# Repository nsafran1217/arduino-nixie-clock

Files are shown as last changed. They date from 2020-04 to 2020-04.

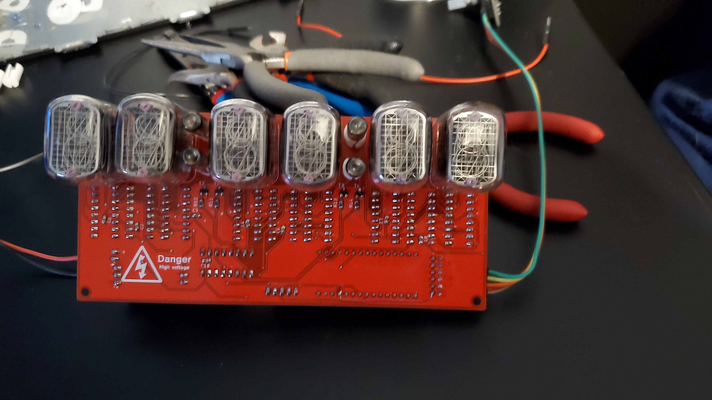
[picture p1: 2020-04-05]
top.jpg

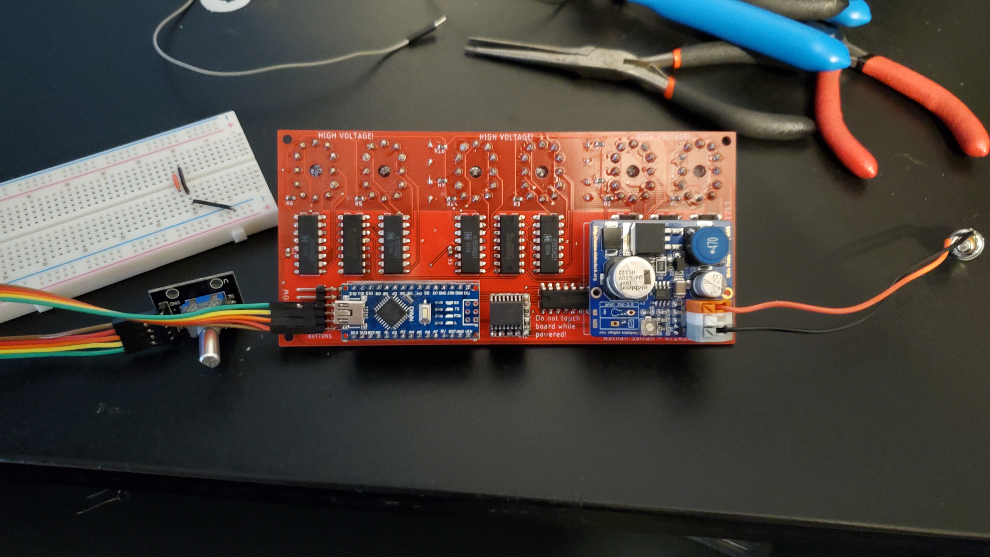
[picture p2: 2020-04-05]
back.jpg

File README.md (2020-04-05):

# arduino-nixie-clock
Custom IN-12A (ИН-12А) Nixie clock with RTC and arduino

This code is messy and specific to my board design. 

I made one change after recieving the boards. I needed a 5volt power pin for the rotary encoder. I scrapped up a trace to a digital pin on the button header and added a bodge wire for 5 volts. You will need to get 5v to your rotary encoder

https://www.amazon.com/HiLetgo-Degrees-Rotary-Encoder-Arduino/dp/B07WZF1TXX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

# Main Modes
Adjust by turning rotary encoder
* 0: Time mode
* 1: Date mode
* 2: Rotate mode

Rotate mode rotates between date and time at a set interval

# Settings menu
Enter settings menu by pressing rotary encoder

Press it again to change the selected setting

* 0: Exit settings menu
* 1: Set Time
* 2: Set Date
* 3: Set rotation interval in seconds
* 4: Select 12 or 24 hour display
* 5: Set the time transition mode. currently there is only two. 0 for normal and 1 for slot machine effect.
* 6: Set time to turn display off then back on. First digit is the hour it turns off. second is the hour it turns back on
* 7: Set anti cathode poison time. Fist digit is the minute that the first run will happen on. Second is the interval in minutes that it runs

example: 15 - 10. the first run will happen at 0:15 and the next run will happen at 0:25. Add 10 minutes for every run after

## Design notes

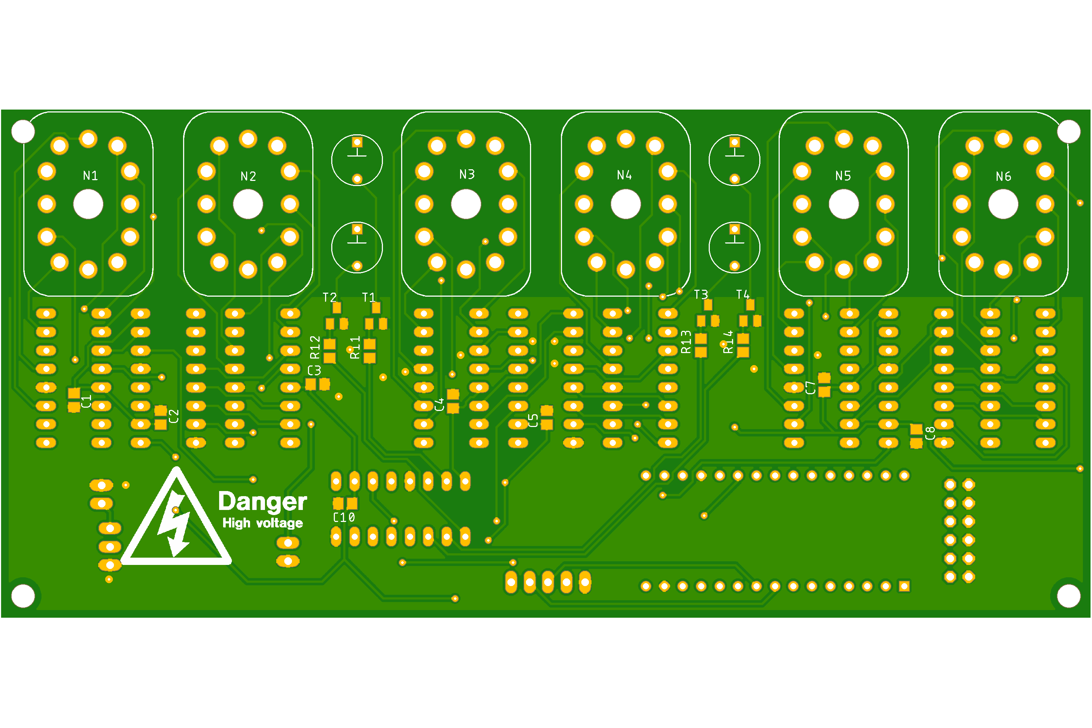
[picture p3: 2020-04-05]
front.png

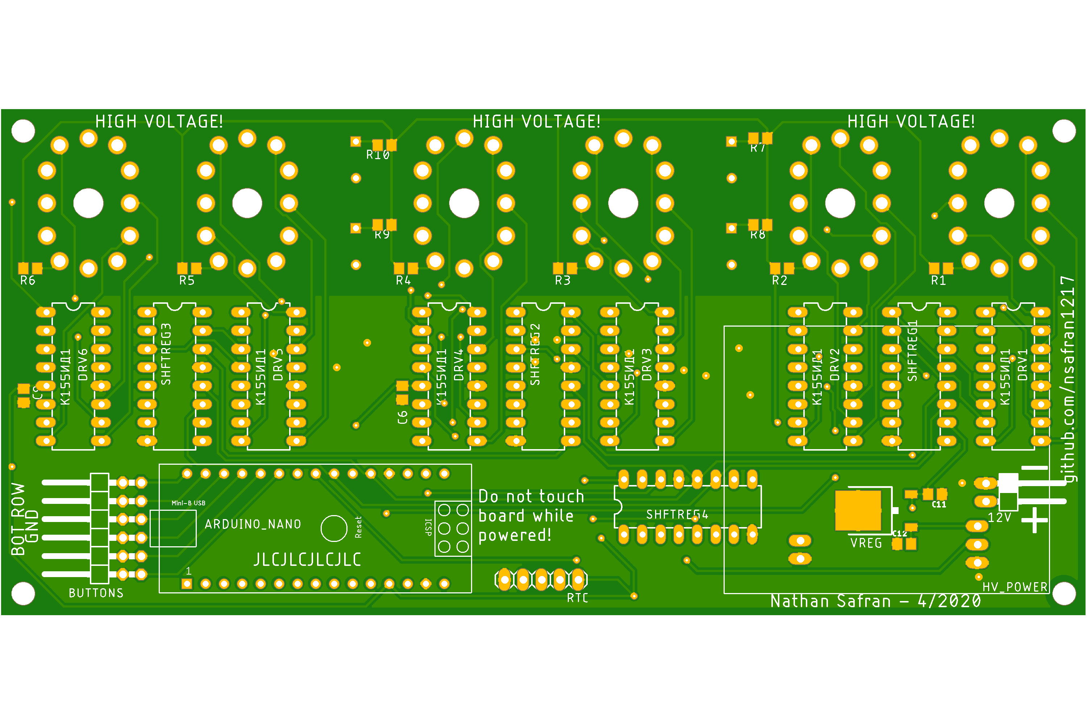
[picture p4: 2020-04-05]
bottom.png

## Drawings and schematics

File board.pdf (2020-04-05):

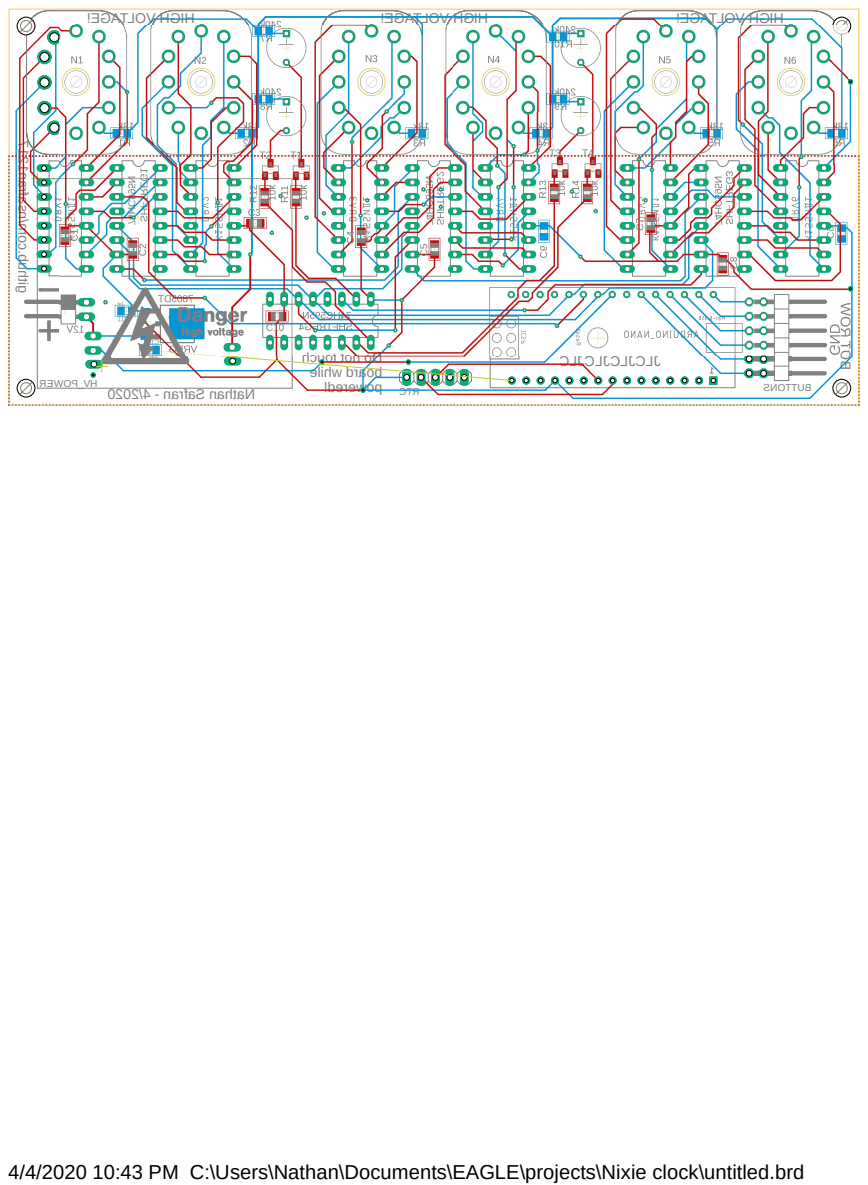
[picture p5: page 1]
BUTTONS HV_POWER RTC; board while powered!

HIGH VOLTAGE! HIGH VOLTAGE! HIGH VOLTAGE!

JLCJLCJLCJLC github.com/nsafran1217

Nathan Safran - 4/2020 BOT ROW

Do not touch

4/4/2020 10:43 PM C:\Users\Nathan\Documents\EAGLE\projects\Nixie clock\untitled.brd

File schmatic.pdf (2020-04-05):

4/4/2020 10:43 PM f=0.57 C:\Users\Nathan\Documents\EAGLE\projects\Nixie clock\untitled.sch (Sheet: 1/1) К155ИД¹ | К155ИД¹ | К155ИД¹ | К155ИД¹ | К155ИД¹ | К155ИД¹ 74HC⁵⁹⁵N | 74HC⁵⁹⁵N | 74HC⁵⁹⁵N +5V | GNDGND | GND | GND

# INS-1

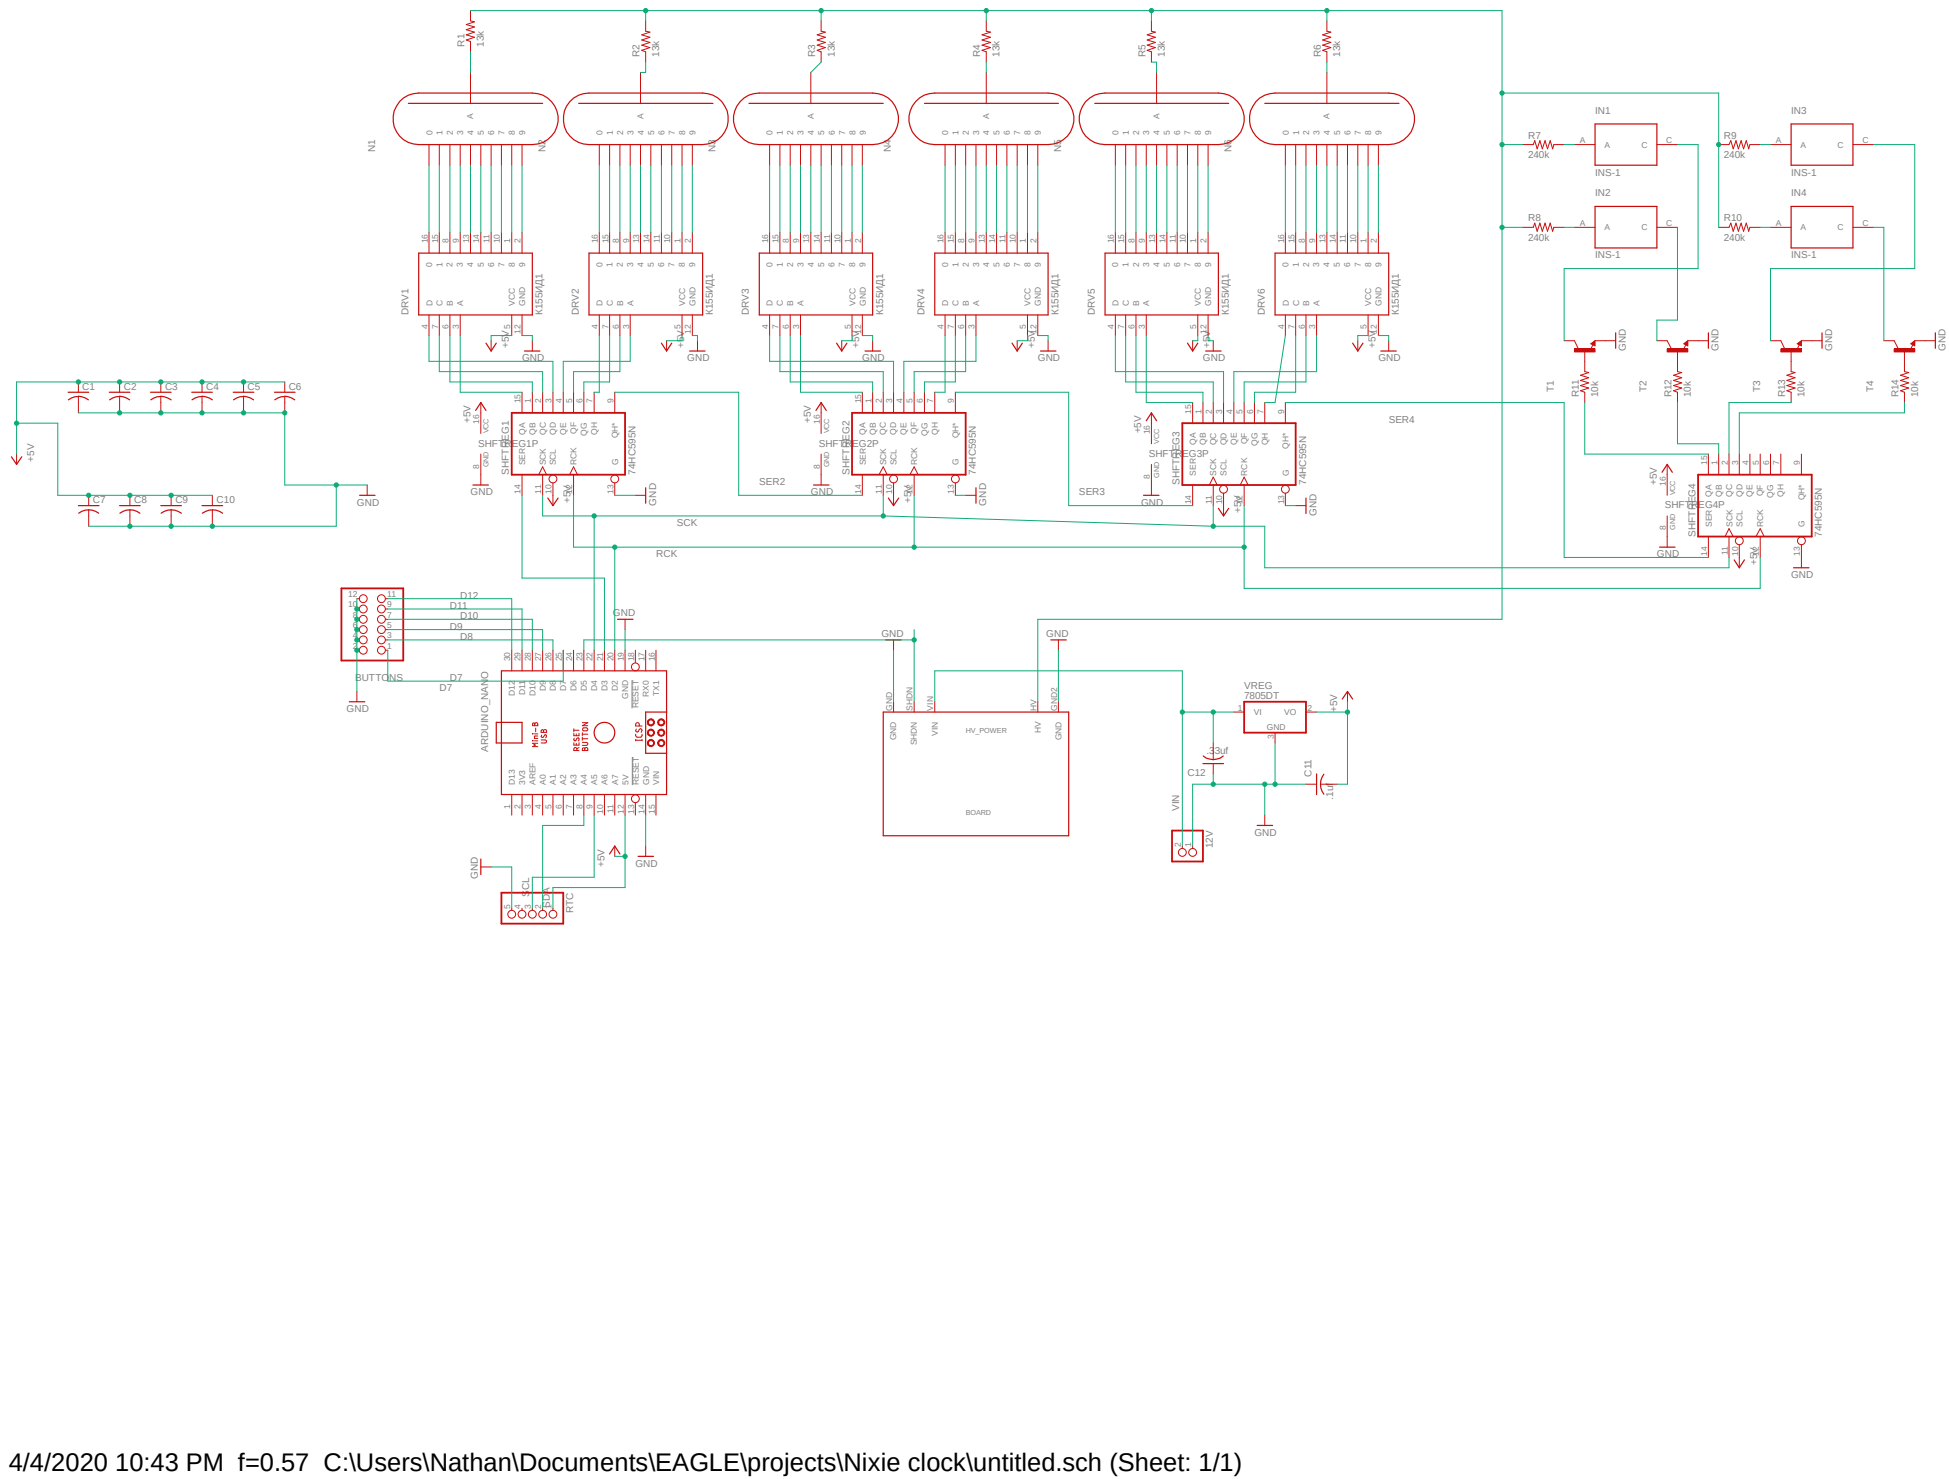
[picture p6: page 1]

7 SCL 10 SCK 11 RCK 12 G 13 SER 14 QA 15 QH* 9 SHFTREG4 R11 R12 R13 R14 8 16 GND VCC SHFTREG1P 8 16 GND VCC SHFTREG2P 8 16 GND VCC SHFTREG3P 8 16 GND VCC SHFTREG4P C1 C2 C3 C4 C5 C6 T1T2T3T4

7 SCL 10 SCK 11 RCK 12 G 13 SER 14 QA 15 QH* 9 SHFTREG1 QB

7 SCL 10 SCK 11 RCK 12 G 13 SER 14 QA 15 QH* 9 SHFTREG3 TX1 16 RX0 17 RESET 18 GND 19 D2 20 D3 21 D4 22 D5 23 D6 24 D7 25 D8 26 D9 27 D10 28 D11 29 D12 30 D13

7 SCL 10 SCK 11 RCK 12 G 13 SER 14 QA 15 QH* 9 SHFTREG2 QB

9 A6 10 A7 11 5V 12 RESET 13 GND 14 VIN 15 ARDUINO_NANO GND GND SHDN SHDN VIN VIN HV HV GND GND2 HV_POWER

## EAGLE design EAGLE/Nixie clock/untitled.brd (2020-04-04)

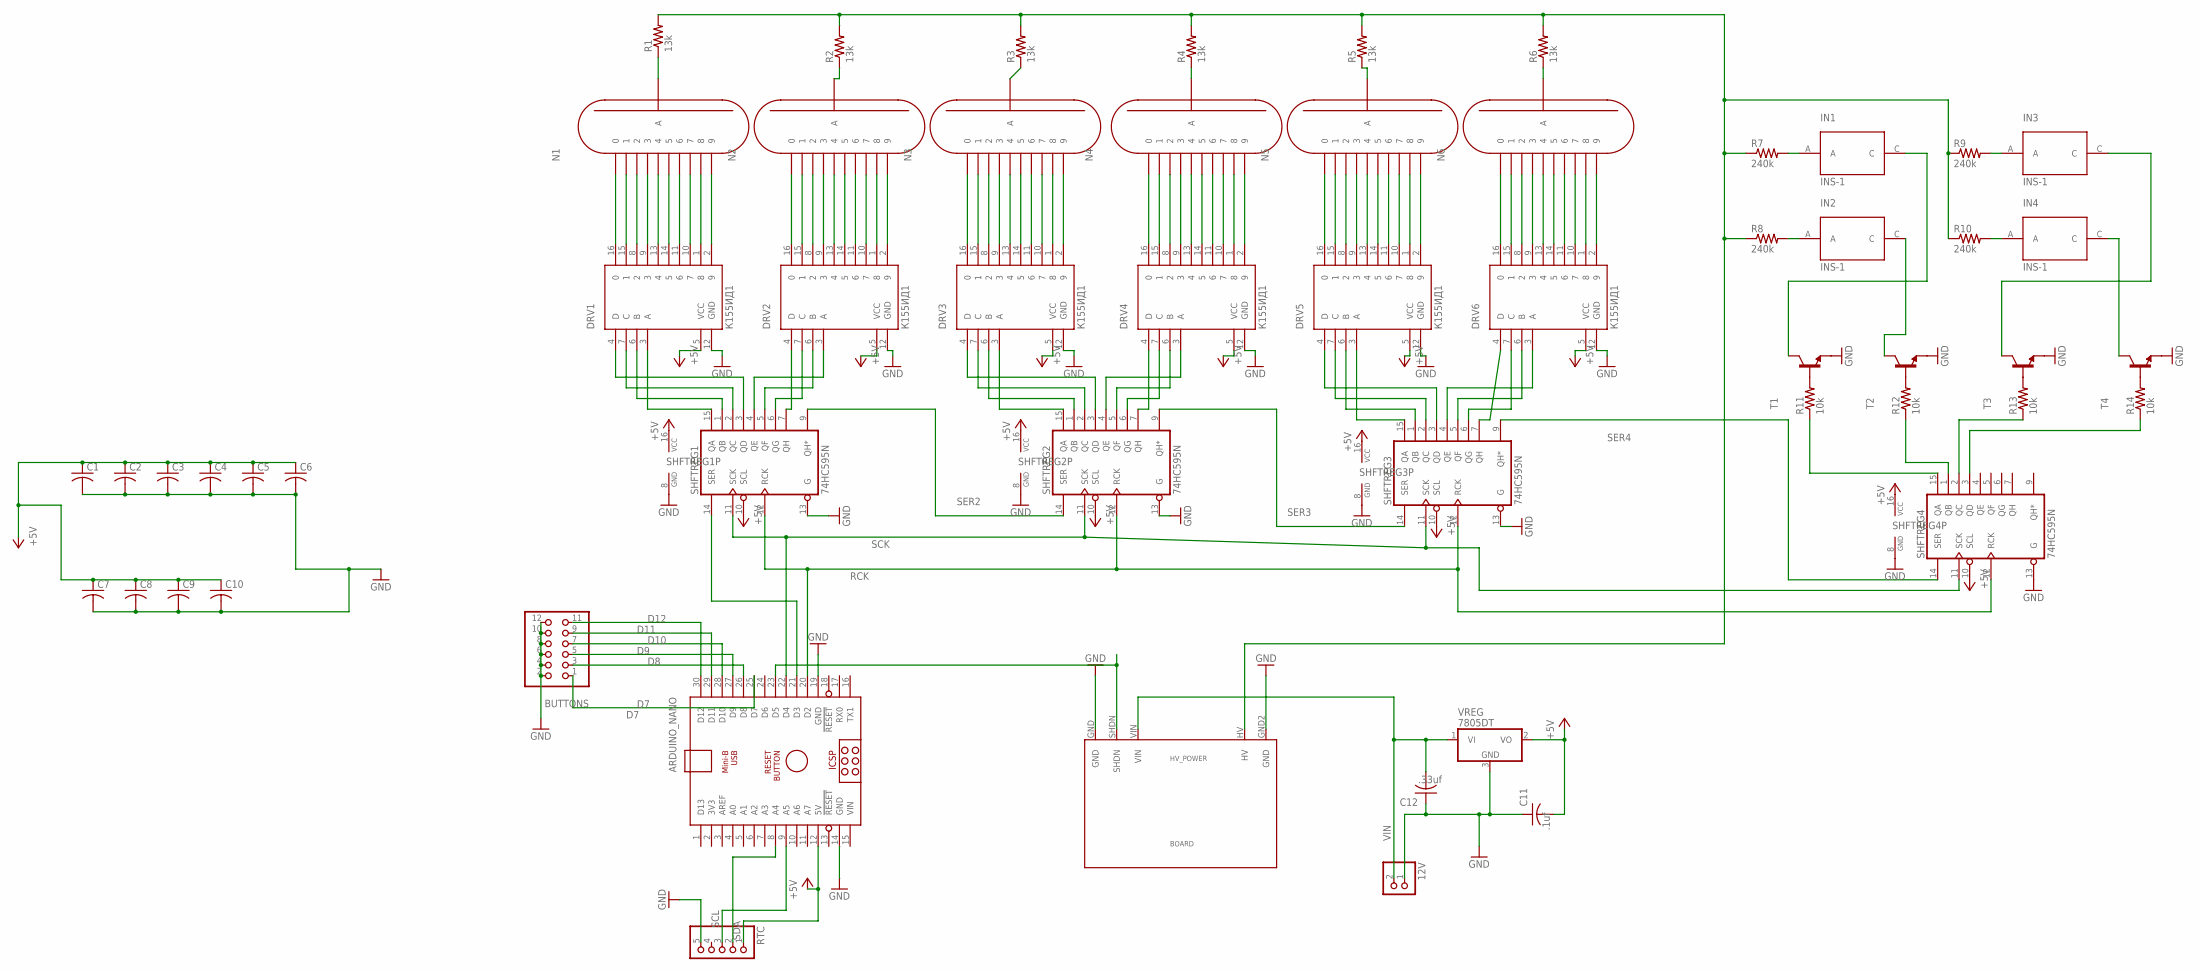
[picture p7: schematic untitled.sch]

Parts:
12V: PINHD-1X2/90; 1X02/90
ARDUINO_NANO: ARDUINO_NANO
BUTTONS: PINHD-2X6/90; 2X06/90
C1, C2, C3, C4, C5, C6, C7, C8, C9, C10: C-USC0805; C0805
C11: .1uf; C0805
C12: .33uf; C0805
DRV1, DRV2, DRV3, DRV4, DRV5, DRV6: К155ИД1; DIL16
HV_POWER: BOARD
IN1, IN2, IN3, IN4: INS-1
N1, N2, N3, N4, N5, N6: IN-12A; IN-12
R1, R2, R3, R4, R5, R6: 13k; R0805
R7, R8, R9, R10: 240k; R0805
R11, R12, R13, R14: 10k; R0805
RTC: PINHD-1X5; 1X05
SHFTREG1, SHFTREG2, SHFTREG3, SHFTREG4: 74HC595N; DIL16
T1, T2, T3, T4: MMBTA42LT1-NPN-SOT23-BEC; SOT23-BEC
VREG: 7805DT; TO252

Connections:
+5V: ARDUINO_NANO.12 (5V), C1.1, C2.1, C3.1, C4.1, C5.1, C6.1, C7.1, C8.1, C9.1, C10.1, C11.2, DRV1.5 (VCC), DRV2.5 (VCC), DRV3.5 (VCC), DRV4.5 (VCC), DRV5.5 (VCC), DRV6.5 (VCC), RTC.1, SHFTREG1.10 (SCL), SHFTREG1.16 (VCC), SHFTREG2.10 (SCL), SHFTREG2.16 (VCC), SHFTREG3.10 (SCL), SHFTREG3.16 (VCC), SHFTREG4.10 (SCL), SHFTREG4.16 (VCC), VREG.2 (VO)
D7: ARDUINO_NANO.25 (D7), BUTTONS.1
D8: ARDUINO_NANO.26 (D8), BUTTONS.3
D9: ARDUINO_NANO.27 (D9), BUTTONS.5
D10: ARDUINO_NANO.28 (D10), BUTTONS.7
D11: ARDUINO_NANO.29 (D11), BUTTONS.9
D12: ARDUINO_NANO.30 (D12), BUTTONS.11
GND: 12V.1, ARDUINO_NANO.14 (GND), ARDUINO_NANO.19 (GND), BUTTONS.2, BUTTONS.4, BUTTONS.6, BUTTONS.8, BUTTONS.10, BUTTONS.12, C1.2, C2.2, C3.2, C4.2, C5.2, C6.2, C7.2, C8.2, C9.2, C10.2, C11.1, C12.1, DRV1.12 (GND), DRV2.12 (GND), DRV3.12 (GND), DRV4.12 (GND), DRV5.12 (GND), DRV6.12 (GND), HV_POWER.GND, HV_POWER.GND2 (GND), RTC.5, SHFTREG1.8 (GND), SHFTREG1.13 (G), SHFTREG2.8 (GND), SHFTREG2.13 (G), SHFTREG3.8 (GND), SHFTREG3.13 (G), SHFTREG4.8 (GND), SHFTREG4.13 (G), T1.E, T2.E, T3.E, T4.E, VREG.3 (GND)
unnamed: DRV4.4 (D), SHFTREG2.7 (QH)
unnamed: DRV1.16 (0), N1.0
unnamed: DRV1.15 (1), N1.1
unnamed: DRV1.8 (2), N1.2
unnamed: DRV1.9 (3), N1.3
unnamed: DRV1.13 (4), N1.4
unnamed: DRV1.11 (6), N1.6
unnamed: DRV1.14 (5), N1.5
unnamed: DRV1.10 (7), N1.7
unnamed: DRV1.1 (8), N1.8
unnamed: DRV1.2 (9), N1.9
unnamed: DRV2.16 (0), N2.0
unnamed: DRV2.15 (1), N2.1
unnamed: DRV2.8 (2), N2.2
unnamed: DRV2.9 (3), N2.3
unnamed: DRV2.13 (4), N2.4
unnamed: DRV2.14 (5), N2.5
unnamed: DRV2.11 (6), N2.6
unnamed: DRV2.10 (7), N2.7
unnamed: DRV2.1 (8), N2.8
unnamed: DRV2.2 (9), N2.9
unnamed: DRV3.16 (0), N3.0
unnamed: DRV3.15 (1), N3.1
unnamed: DRV3.8 (2), N3.2
unnamed: DRV3.9 (3), N3.3
unnamed: DRV3.13 (4), N3.4
unnamed: DRV3.14 (5), N3.5
unnamed: DRV3.11 (6), N3.6
unnamed: DRV3.10 (7), N3.7
unnamed: DRV3.1 (8), N3.8
unnamed: DRV3.2 (9), N3.9
unnamed: DRV4.16 (0), N4.0
unnamed: DRV4.15 (1), N4.1
unnamed: DRV4.8 (2), N4.2
unnamed: DRV4.9 (3), N4.3
unnamed: DRV4.13 (4), N4.4
unnamed: DRV4.14 (5), N4.5
unnamed: DRV4.11 (6), N4.6
unnamed: DRV4.10 (7), N4.7
unnamed: DRV4.1 (8), N4.8
unnamed: DRV4.2 (9), N4.9
unnamed: DRV5.16 (0), N5.0
unnamed: DRV5.15 (1), N5.1
unnamed: DRV5.8 (2), N5.2
unnamed: DRV5.9 (3), N5.3
unnamed: DRV5.13 (4), N5.4
unnamed: DRV5.11 (6), N5.6
unnamed: DRV5.14 (5), N5.5
unnamed: DRV5.10 (7), N5.7
unnamed: DRV5.1 (8), N5.8
unnamed: DRV5.2 (9), N5.9
unnamed: DRV6.16 (0), N6.0
unnamed: DRV6.15 (1), N6.1
unnamed: DRV6.8 (2), N6.2
unnamed: DRV6.9 (3), N6.3
unnamed: DRV6.13 (4), N6.4
unnamed: DRV6.14 (5), N6.5
unnamed: DRV6.11 (6), N6.6
unnamed: DRV6.10 (7), N6.7
unnamed: DRV6.1 (8), N6.8
unnamed: DRV1.3 (A), SHFTREG1.15 (QA)
unnamed: DRV1.6 (B), SHFTREG1.1 (QB)
unnamed: DRV1.7 (C), SHFTREG1.2 (QC)
unnamed: DRV1.4 (D), SHFTREG1.3 (QD)
unnamed: DRV2.3 (A), SHFTREG1.4 (QE)
unnamed: DRV2.6 (B), SHFTREG1.5 (QF)
unnamed: DRV2.7 (C), SHFTREG1.6 (QG)
unnamed: DRV2.4 (D), SHFTREG1.7 (QH)
unnamed: ARDUINO_NANO.23 (D5), HV_POWER.SHDN
unnamed: DRV3.3 (A), SHFTREG2.15 (QA)
unnamed: DRV3.6 (B), SHFTREG2.1 (QB)
unnamed: DRV3.7 (C), SHFTREG2.2 (QC)
unnamed: DRV3.4 (D), SHFTREG2.3 (QD)
unnamed: DRV4.3 (A), SHFTREG2.4 (QE)
unnamed: DRV4.6 (B), SHFTREG2.5 (QF)
unnamed: DRV4.7 (C), SHFTREG2.6 (QG)
unnamed: DRV6.2 (9), N6.9
unnamed: DRV5.3 (A), SHFTREG3.15 (QA)
unnamed: DRV5.6 (B), SHFTREG3.1 (QB)
unnamed: DRV5.7 (C), SHFTREG3.2 (QC)
unnamed: DRV5.4 (D), SHFTREG3.3 (QD)
unnamed: DRV6.3 (A), SHFTREG3.4 (QE)
unnamed: DRV6.6 (B), SHFTREG3.5 (QF)
unnamed: DRV6.7 (C), SHFTREG3.6 (QG)
unnamed: DRV6.4 (D), SHFTREG3.7 (QH)
unnamed: IN1.C, T1.C
unnamed: N1.A, R1.1
unnamed: N2.A, R2.1
unnamed: N3.A, R3.1
unnamed: N4.A, R4.1
unnamed: N5.A, R5.1
unnamed: N6.A, R6.1
unnamed: IN2.A, R8.2
unnamed: IN1.A, R7.2
unnamed: IN3.A, R9.2
unnamed: IN4.A, R10.2
unnamed: HV_POWER.HV, R1.2, R2.2, R3.2, R4.2, R5.2, R6.2, R7.1, R8.1, R9.1, R10.1
unnamed: R11.2, T1.B
unnamed: R12.2, T2.B
unnamed: R13.2, T3.B
unnamed: R11.1, SHFTREG4.15 (QA)
unnamed: R12.1, SHFTREG4.1 (QB)
unnamed: IN3.C, T3.C
unnamed: R13.1, SHFTREG4.2 (QC)
unnamed: R14.1, SHFTREG4.3 (QD)
unnamed: IN4.C, T4.C
unnamed: R14.2, T4.B
unnamed: IN2.C, T2.C
RCK: ARDUINO_NANO.20 (D2), SHFTREG1.12 (RCK), SHFTREG2.12 (RCK), SHFTREG3.12 (RCK), SHFTREG4.12 (RCK)
SCK: ARDUINO_NANO.22 (D4), SHFTREG1.11 (SCK), SHFTREG2.11 (SCK), SHFTREG3.11 (SCK), SHFTREG4.11 (SCK)
SCL: ARDUINO_NANO.9 (A5), RTC.3
SDA: ARDUINO_NANO.8 (A4), RTC.2
SER1: ARDUINO_NANO.21 (D3), SHFTREG1.14 (SER)
SER2: SHFTREG1.9 (QH*), SHFTREG2.14 (SER)
SER3: SHFTREG2.9 (QH*), SHFTREG3.14 (SER)
SER4: SHFTREG3.9 (QH*), SHFTREG4.14 (SER)
VIN: 12V.2, ARDUINO_NANO.15 (VIN), C12.2, HV_POWER.VIN, VREG.1 (VI)

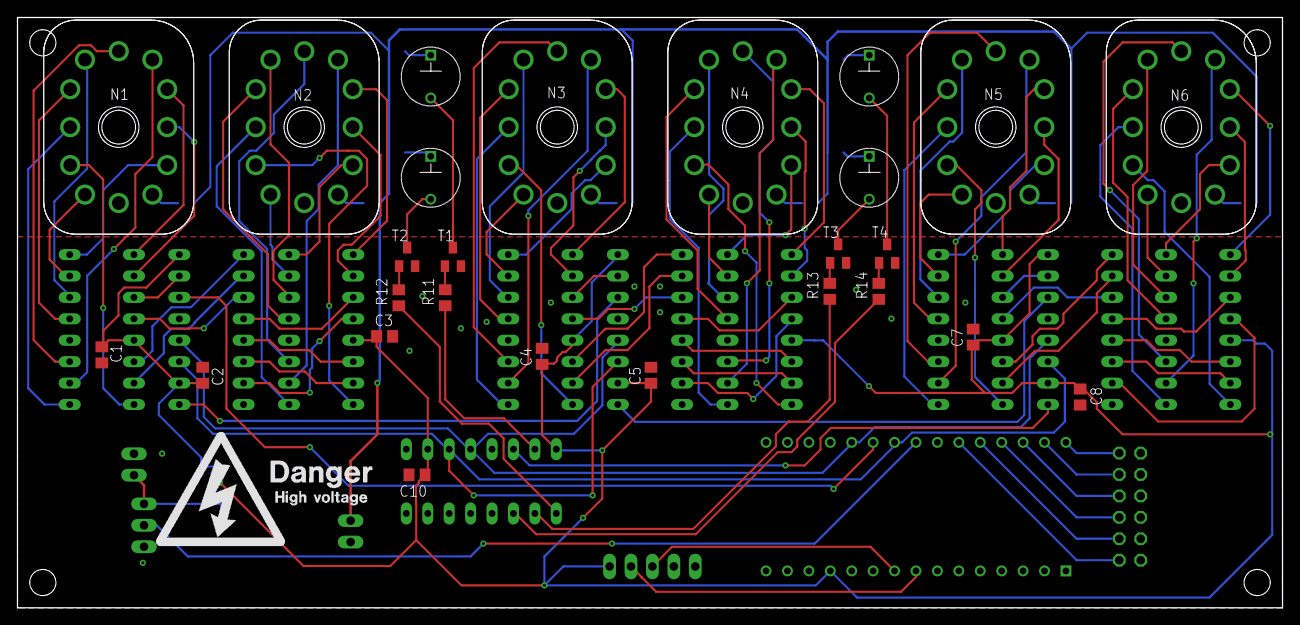
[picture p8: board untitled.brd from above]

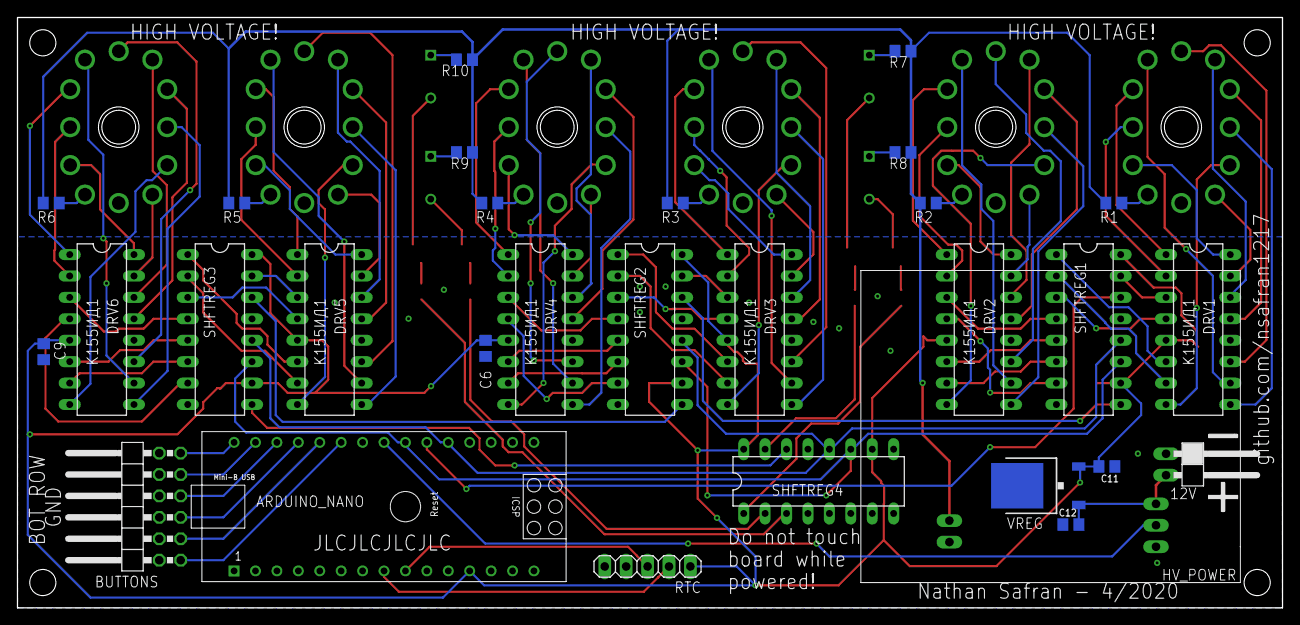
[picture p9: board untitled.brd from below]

Board: 2 copper layers, 150.0 x 70.0 mm, 57 parts (30 on the bottom side), 125 nets.

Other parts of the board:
U$1: HV

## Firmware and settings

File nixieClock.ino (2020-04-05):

//Made by Nathan Safran 4/4/2020
//https://github.com/nsafran1217

#include <Wire.h>
#include <RTClib.h>
#include <EEPROM.h>

// DO NOT CHANGE, PIN ASSIGNMENTS
#define LATCHPIN 2
#define DATAPIN 3
#define CLOCKPIN 4
#define ROTCLKPIN 10
#define ROTDTPIN 9
#define ROTBTTNPIN 8
#define SHTDNPIN 5

//EEPROM ADDRESSES
#define twelveHourModeADDRESS 0
#define ROTATETIMEADDRESS 1
#define TRANSMODEADDRESS 2
#define ONHOURADDRESS 3
#define OFFHOURADDRESS 4
#define poisonTimeSpanADDRESS 5
#define poisonTimeStartADDRESS 6

RTC_DS3231 rtc; //init RTC

int hour, minute, second, year, month, day;
int colons;

int currentStateCLK;
int lastStateCLK;
unsigned long lastButtonPress = 0;

int rotatespeed = EEPROM.read(ROTATETIMEADDRESS);            //time in seconds, min 4, max 59
boolean twelveHourMode = EEPROM.read(twelveHourModeADDRESS); //0 for 12, 1 for 24
int TransMode = EEPROM.read(TRANSMODEADDRESS);
int onHour = EEPROM.read(ONHOURADDRESS);
int offHour = EEPROM.read(OFFHOURADDRESS);
int poisonTimeSpan = EEPROM.read(poisonTimeSpanADDRESS);
int poisonTimeStart = EEPROM.read(poisonTimeStartADDRESS);
int nextPoisonRun;
boolean dateOrTime = false;
boolean displayOff = false;
unsigned long lastBlinkTime = 0; //for flashing display/digits
unsigned long blinkTime = 500;
unsigned long waitForDisplay = 0; //for displaying mode
int nextSwitch = 0;
int displayMode = 0;
//0  Time
//1  Date
//2  Rotate time and date

int lastHourTen, lastHourOne, lastMinuteTen, lastMinuteOne, lastSecondTen, lastSecondOne; //for scroll mode
int HourTen, HourOne, MinuteTen, MinuteOne, SecondTen, SecondOne;
int secondsCombined, minutesCombined, hoursCombined;

void setup()
{
  Serial.begin(57600); //DEBUG

  rtc.begin();
  pinMode(LATCHPIN, OUTPUT);
  pinMode(CLOCKPIN, OUTPUT);
  pinMode(DATAPIN, OUTPUT);
  pinMode(SHTDNPIN, OUTPUT);
  pinMode(ROTCLKPIN, INPUT);
  pinMode(ROTDTPIN, INPUT);
  pinMode(ROTBTTNPIN, INPUT);
  digitalWrite(ROTBTTNPIN, HIGH);

  lastStateCLK = digitalRead(ROTCLKPIN);
  getDateTime();
  lastHourTen = (hour / 10) % 10;
  lastHourOne = hour % 10;
  lastMinuteTen = (minute / 10) % 10;
  lastMinuteOne = minute % 10;
  lastSecondTen = (second / 10) % 10;
  lastSecondOne = second % 10;
  nextPoisonRun = poisonTimeStart + poisonTimeSpan;
  while (minute > nextPoisonRun)
  {
    nextPoisonRun = nextPoisonRun + poisonTimeSpan;
    if (nextPoisonRun > 59)
    {
      nextPoisonRun = nextPoisonRun - 60;
    }
  }
}

int readRotEncoder(int counter) //takes a counter in and spits it back out if it changes
{
  // Read the current state of CLK
  currentStateCLK = digitalRead(ROTCLKPIN);
  // If last and current state of CLK are different, then pulse occurred
  // React to only 1 state change to avoid double count
  if (currentStateCLK != lastStateCLK && currentStateCLK == 1)
  {
    // the encoder is rotating CCW so decrement
    if (digitalRead(ROTDTPIN) != currentStateCLK)
    {
      counter--;
    }
    else
    {
      // Encoder is rotating CW so increment
      counter++;
    }
  }
  // Remember last CLK state
  lastStateCLK = currentStateCLK;
  return counter;
}
boolean readRotButton() //true if button pressed
{
  // Read the button state
  int btnState = digitalRead(ROTBTTNPIN);
  //If we detect LOW signal, button is pressed
  if (btnState == LOW)
  {
    //if 50ms have passed since last LOW pulse, it means that the
    //button has been pressed, released and pressed again
    if (millis() - lastButtonPress > 50)
    {
      lastButtonPress = millis();
      return true;
    }
    else
    {
      lastButtonPress = millis();
      return false;
    }
    // Remember last button press event
  }
  else
  {
    return false;
  }
}

int changeMode(int mode, int numOfModes) //numofmodes starts at 0! display mode on tube, easy for selecting
{
  int lastmode = mode;
  mode = readRotEncoder(mode);
  if (mode > numOfModes) //if mode invalid, loop around
  {
    mode = 0;
  }
  else if (mode < 0)
  {
    mode = numOfModes;
  }
  if (mode != lastmode)
  {
    waitForDisplay = millis();
    while (millis() - waitForDisplay < 500)
    {
      delay(5);
      writeToNixie(mode, 255, 255, 0);
      mode = changeMode(mode, numOfModes);
    }
  }
  return mode;
}
void loop()
{
  delay(5);
  getDateTime();
  if (hour == offHour && onHour != offHour && !displayOff) ///turn off power supply
  {
    displayOff = !displayOff;
    
  }
  if (hour == onHour && onHour != offHour && displayOff) ///turn back on
  {
    displayOff = !displayOff;
  }

  if (displayOff){
    digitalWrite(SHTDNPIN, HIGH);
    delay(10000);
  } else{
    digitalWrite(SHTDNPIN, LOW);
  }

  if (minute == nextPoisonRun)
  {
    antiPoison();
    nextPoisonRun = nextPoisonRun + poisonTimeSpan;
    if (nextPoisonRun > 59)
    {
      nextPoisonRun = nextPoisonRun - 60;
    }
  }

  if (readRotButton()) //enter settings menu
  {
    settingsMenu();
  }
  displayMode = changeMode(displayMode, 2);
  switch (displayMode)
  {
  case 0:
    if (TransMode == 0)
    {
      normalTimeMode();
    }
    else if (TransMode == 1)
    {
      scrollTimeMode();
    }

    break;
  case 1:
    dateMode();
    break;
  case 2:
    rotateMode();
    break;
  }
}

void settingsMenu()
{
  int settingsMode = 0;
  boolean exitSettings = false;
  lastBlinkTime = millis();
  while (!exitSettings)
  {
    delay(5);
    settingsMode = displayMode = changeMode(displayMode, 7);
    switch (settingsMode)
    {
    case 0: //exit, just have number
      writeToNixie(settingsMode, 255, 255, 0);
      break;
    case 1: //change time
      if ((millis() - lastBlinkTime) < blinkTime)
      {
        writeToNixie(hour, minute, second, 15);
      }
      else if (((millis() - lastBlinkTime) > blinkTime * 2))
      {
        writeToNixie(hour, minute, second, 15);
        lastBlinkTime = millis(); //reset timer
      }
      else
      {
        writeToNixie(255, 255, 255, 15);
      }
      break;
    case 2: //change date
      if ((millis() - lastBlinkTime) < blinkTime)
      {
        writeToNixie(month, day, year, 6);
      }
      else if (((millis() - lastBlinkTime) > blinkTime * 2))
      {
        writeToNixie(month, day, year, 6);
        lastBlinkTime = millis(); //reset timer
      }
      else
      {
        writeToNixie(255, 255, 255, 15);
      }
      break;
    case 3: //set date time rotation speed
      writeToNixie(settingsMode, 255, rotatespeed, 0);
      break;
    case 4: //setHourDisplay
      if (twelveHourMode)
      {
        writeToNixie(settingsMode, 255, 12, 0);
      }
      else
      {
        writeToNixie(settingsMode, 255, 24, 0);
      }
      break;
    case 5: //set setTransitionMode
      writeToNixie(settingsMode, 255, TransMode, 0);
      break;
    case 6: //set on off time for display
      writeToNixie(settingsMode, offHour, onHour, 8);
      break;
    case 7:
      writeToNixie(settingsMode, poisonTimeStart, poisonTimeSpan, 8);
      break;
    }

    if (readRotButton())
    {
      switch (settingsMode)
      {
      case 0:
        exitSettings = true; //exit back to display mode
        break;
      case 1:
        setTime();
        break;
      case 2:
        setDate();
        break;
      case 3:
        setRotationSpeed();
        break;
      case 4:
        setHourDisplay();
        break;
      case 5:
        setTransitionMode();
        break;
      case 6:
        setOnOffTime();
        break;
      case 7:
        setAntiPoisonMinute();
        break;
      }
    }
  }
}
void normalTimeMode()
{
  if (second % 2 == 0) //too slow, change to millis timer for 500 milliseconds
  {
    colons = 15;
  }
  else
  {
    colons = 0;
  }
  if (twelveHourMode)
  {
    if (hour > 12)
    {
      writeToNixie(hour - 12, minute, second, colons);
    }
    else if (hour == 00)
    {
      writeToNixie(12, minute, second, colons);
    }

    else
    {
      writeToNixie(hour, minute, second, colons);
    }
  }
  else
  {
    writeToNixie(hour, minute, second, colons);
  }
}

void scrollTimeMode()
{
  if (second % 2 == 0) //too slow, change to millis timer for 500 milliseconds
  {
    colons = 15;
  }
  else
  {
    colons = 0;
  }
  if (twelveHourMode)
  {
    if (hour > 12)
    {
      writeToNixieScroll(hour - 12, minute, second, colons);
    }
    else if (hour == 00)
    {
      writeToNixieScroll(12, minute, second, colons);
    }

    else
    {
      writeToNixieScroll(hour, minute, second, colons);
    }
  }
  else
  {
    writeToNixieScroll(hour, minute, second, colons); //////debug change
  }
}

void dateMode()
{
  //printtime(); //debug
  if (second % 2 == 0) //too slow, change to millis timer for 500 milliseconds
  {
    colons = 6;
  }
  else
  {
    colons = 0;
  }
  writeToNixie(month, day, year, colons);
}
void rotateMode()
{
  if (second == nextSwitch)
  {
    nextSwitch = ((second + rotatespeed) % 60);
    dateOrTime = !dateOrTime;
  }
  if (dateOrTime)
  {
    normalTimeMode(); /////////////////maybe change
  }
  else
  {
    dateMode();
  }
}
void antiPoison()
{
  int j;
  for (int i = 0; i < 10; i++)
  {
    j = i | ((i) << 4);
    writeToNixieRAW(j, j, j, 15);
    delay(1000);
  }
}
void setTime()
{
  int lasthour, lastminute, lastsecond;
  int digitMod = 0;
  lastBlinkTime = millis();
  while (digitMod < 3)
  {
    lasthour = hour;
    lastminute = minute;
    lastsecond = second;
    delay(5);
    if (readRotButton())
    {
      lastBlinkTime = millis(); //reset timer
      digitMod++;
    }
    if ((millis() - lastBlinkTime) < blinkTime)
    {

      writeToNixie(hour, minute, second, 15);
    }
    else if (((millis() - lastBlinkTime) > blinkTime * 2))
    {
      writeToNixie(hour, minute, second, 15);
      lastBlinkTime = millis(); //reset timer
    }
    else
    {
      //switch off
      switch (digitMod)
      {
      case 0:
        writeToNixie(255, minute, second, 15); //255 will blank the display
        break;
      case 1:
        writeToNixie(hour, 255, second, 15);
        break;
      case 2:
        writeToNixie(hour, minute, 255, 15);
        break;
      }
    }

    switch (digitMod)
    {
    case 0:
      hour = readRotEncoder(hour);
      if (hour != lasthour)
      {
        lastBlinkTime = millis(); //reset timer
        if (hour > 23)
        {
          hour = 0;
        }
        else if (hour < 0)
        {
          hour = 23;
        }
      }
      break;
    case 1:
      minute = readRotEncoder(minute);
      if (minute != lastminute)
      {
        lastBlinkTime = millis(); //reset timer
        if (minute > 59)
        {
          minute = 0;
        }
        else if (minute < 0)
        {
          minute = 59;
        }
      }
      break;
    case 2:
      second = readRotEncoder(second);
      if (second != lastsecond)
      {
        lastBlinkTime = millis(); //reset timer
        if (second > 59)
        {
          second = 0;
        }
        else if (second < 0)
        {
          second = 59;
        }
      }
      break;
    }
  }
  rtc.adjust(DateTime(year, month, day, hour, minute, second));
}
void setDate()
{
  int lastyear, lastmonth, lastday;
  int digitMod = 0;
  lastBlinkTime = millis();
  while (digitMod < 3)
  {
    lastyear = year;
    lastmonth = month;
    lastday = day;
    delay(5);
    if (readRotButton())
    {
      lastBlinkTime = millis(); //reset timer
      digitMod++;
    }
    if (digitMod == 2)
    {
      writeToNixie(255, year / 100, year % 100, 6);
    }
    else
    {
      if ((millis() - lastBlinkTime) < blinkTime)
      {

        writeToNixie(month, day, year, 6);
      }
      else if (((millis() - lastBlinkTime) > blinkTime * 2))
      {
        writeToNixie(month, day, year, 6);
        lastBlinkTime = millis(); //reset timer
      }
      else
      {
        //switch off
        switch (digitMod)
        {
        case 0:
          writeToNixie(255, day, year, 6); //255 will blank the display
          break;
        case 1:
          writeToNixie(month, 255, year, 6);
          break;
        }
      }
    }

    switch (digitMod)
    {
    case 0:
      month = readRotEncoder(month);
      if (month != lastmonth)
      {
        lastBlinkTime = millis(); //reset timer
        if (month > 12)
        {
          month = 1;
        }
        else if (month < 1)
        {
          month = 12;
        }
      }
      break;
    case 1:
      day = readRotEncoder(day);
      if (day != lastday)
      {
        lastBlinkTime = millis(); //reset timer
        if (day > 31)
        {
          day = 1;
        }
        else if (day < 1)
        {
          day = 31;
        }
      }
      break;
    case 2:
      year = readRotEncoder(year);
      if (year != lastyear)
      {
        lastBlinkTime = millis(); //reset timer
        if (year > 2100)
        {
          year = 2100;
        }
        else if (year < 2020)
        {
          year = 2020;
        }
      }
      break;
    }
  }
  DateTime now = rtc.now();
  hour = now.hour();
  minute = now.minute();
  second = now.second();
  rtc.adjust(DateTime(year, month, day, hour, minute, second));
}
void setHourDisplay()
{
  boolean origBool = twelveHourMode;
  int counter = 0;
  if (twelveHourMode)
  {
    counter = 1;
  }
  while (!readRotButton())
  {
    delay(10);
    counter = readRotEncoder(counter);
    if (counter % 2 == 0)
    {
      twelveHourMode = false;
    }
    else
    {
      twelveHourMode = true;
    }
    if (twelveHourMode)
    {
      writeToNixie(255, 255, 12, 0);
    }
    else
    {
      writeToNixie(255, 255, 24, 0);
    }
  }
  if (origBool != twelveHourMode) //thi sis not working
  {
    EEPROM.write(twelveHourModeADDRESS, (boolean)twelveHourMode); //commmit change to EEPROM
  }
}
void setRotationSpeed()
{
  int origRotateSpeed = rotatespeed;
  while (!readRotButton())
  {
    delay(5);
    rotatespeed = readRotEncoder(rotatespeed);
    if (rotatespeed > 59)
    {
      rotatespeed = 59;
    }
    writeToNixie(255, 255, rotatespeed, 0);
  }
  if (origRotateSpeed != rotatespeed)
  {
    EEPROM.write(ROTATETIMEADDRESS, rotatespeed); //commit change to EEPROM
  }
}

void setTransitionMode()
{
  int origTransMode = TransMode;
  while (!readRotButton())
  {
    delay(10);
    TransMode = readRotEncoder(TransMode);
    if (TransMode > 1)
    {
      TransMode = 0;
    }
    if (TransMode < 0)
    {
      TransMode = 1;
    }
    writeToNixie(255, 255, TransMode, 0);
  }
  if (origTransMode != TransMode)
  {
    EEPROM.write(TRANSMODEADDRESS, TransMode); //commit change to EEPROM
  }
}
void setOnOffTime() ////////////////////////////////////////////////////////////////////////
{
  int origOffHour = offHour; //
  int origOnHour = onHour;
  int lastOnHour, lastOffHour;
  int varMod = 0;
  lastBlinkTime = millis();
  while (varMod < 2)
  {
    delay(5);
    lastOffHour = offHour;
    lastOnHour = onHour;
    if (readRotButton())
    {
      varMod++;
    }
    if ((millis() - lastBlinkTime) < blinkTime)
    {
      writeToNixie(255, offHour, onHour, 8);
    }
    else if (((millis() - lastBlinkTime) > blinkTime * 2))
    {
      writeToNixie(255, offHour, onHour, 8);
      lastBlinkTime = millis(); //reset timer
    }
    else
    {
      switch (varMod)
      {
      case 0:
        writeToNixie(255, 255, onHour, 8);
        break;
      case 1:
        writeToNixie(255, offHour, 255, 8);
        break;
      }
    }
    switch (varMod)
    {
    case 0:
      offHour = readRotEncoder(offHour); //
      if (offHour != lastOffHour)
      {
        lastBlinkTime = millis(); //reset timer
        if (offHour > 23)
        {
          offHour = 0;
        }
        if (offHour < 0)
        {
          offHour = 23;
        }
      }
      break;
    case 1:
      onHour = readRotEncoder(onHour); //
      if (onHour != lastOnHour)
      {
        lastBlinkTime = millis(); //reset timer
        if (onHour > 23)
        {
          onHour = 0;
        }
        if (onHour < 0)
        {
          onHour = 23;
        }
      }
      break;
    }
  }
  if (origOffHour != offHour)
  {
    EEPROM.write(OFFHOURADDRESS, offHour); //commit change to EEPROM
  }
  if (origOnHour != onHour)
  {
    EEPROM.write(ONHOURADDRESS, onHour); //commit change to EEPROM
  }
}
void setAntiPoisonMinute()
{
  int origpoisonTimeSpan = poisonTimeSpan; //
  int origpoisonTimeStart = poisonTimeStart;
  int lastPoisonTimeStart, lastPoisonTimeSpan;
  int varMod = 0;
  lastBlinkTime = millis();
  while (varMod < 2)
  {
    delay(5);
    lastPoisonTimeStart = poisonTimeStart;
    lastPoisonTimeSpan = poisonTimeSpan;
    if (readRotButton())
    {
      varMod++;
    }
    if ((millis() - lastBlinkTime) < blinkTime)
    {
      writeToNixie(255, poisonTimeStart, poisonTimeSpan, 8);
    }
    else if (((millis() - lastBlinkTime) > blinkTime * 2))
    {
      writeToNixie(255, poisonTimeStart, poisonTimeSpan, 8);
      lastBlinkTime = millis(); //reset timer
    }
    else
    {
      switch (varMod)
      {
      case 0:
        writeToNixie(255, 255, poisonTimeSpan, 8);
        break;
      case 1:
        writeToNixie(255, poisonTimeStart, 255, 8);
        break;
      }
    }
    switch (varMod)
    {
    case 0:
      poisonTimeStart = readRotEncoder(poisonTimeStart); //
      if (poisonTimeStart != lastPoisonTimeStart)
      {
        lastBlinkTime = millis(); //reset timer
        if (poisonTimeStart > 59)
        {
          poisonTimeStart = 0;
        }
        if (poisonTimeStart < 0)
        {
          poisonTimeStart = 59;
        }
      }
      break;
    case 1:
      poisonTimeSpan = readRotEncoder(poisonTimeSpan); //
      if (poisonTimeSpan != lastPoisonTimeSpan)
      {
        lastBlinkTime = millis(); //reset timer
        if (poisonTimeSpan > 59)
        {
          poisonTimeSpan = 0;
        }
        if (poisonTimeSpan < 0)
        {
          poisonTimeSpan = 59;
        }
      }
      break;
    }
  }
  if (origpoisonTimeStart != poisonTimeStart)
  {
    EEPROM.write(poisonTimeStartADDRESS, poisonTimeStart); //commit change to EEPROM
  }
  if (origpoisonTimeSpan != poisonTimeSpan)
  {
    EEPROM.write(poisonTimeSpanADDRESS, poisonTimeSpan); //commit change to EEPROM
  }
}

void getDateTime()
{
  DateTime now = rtc.now();
  hour = now.hour();
  minute = now.minute();
  second = now.second();
  year = now.year();
  month = now.month();
  day = now.day();
}

void writeToNixie(int hours, int minutes, int seconds, int divider) //write data to nixie tubes
{
  //printNixieToSerial(hours, minutes, seconds, divider); //degug
  digitalWrite(LATCHPIN, LOW);
  shiftOut(DATAPIN, CLOCKPIN, MSBFIRST, divider);
  shiftOut(DATAPIN, CLOCKPIN, MSBFIRST, convertToNixe(seconds));
  shiftOut(DATAPIN, CLOCKPIN, MSBFIRST, convertToNixe(minutes));
  shiftOut(DATAPIN, CLOCKPIN, MSBFIRST, convertToNixe(hours));
  digitalWrite(LATCHPIN, HIGH);
}

void writeToNixieRAW(int hours, int minutes, int seconds, int divider) //write data to nixie tubes RAW
{
  //printNixieToSerial(hours, minutes, seconds, divider);
  digitalWrite(LATCHPIN, LOW);
  shiftOut(DATAPIN, CLOCKPIN, MSBFIRST, divider);
  shiftOut(DATAPIN, CLOCKPIN, MSBFIRST, seconds);
  shiftOut(DATAPIN, CLOCKPIN, MSBFIRST, minutes);
  shiftOut(DATAPIN, CLOCKPIN, MSBFIRST, hours);
  digitalWrite(LATCHPIN, HIGH);
}

void writeToNixieScroll(int hours, int minutes, int seconds, int divider) //this will be annoying i need an efficiant way to do this. or brute force it
{                                                                         //this is so messy I hate it

  HourTen = (hours / 10) % 10;
  HourOne = hours % 10;
  MinuteTen = (minutes / 10) % 10;
  MinuteOne = minutes % 10;
  SecondTen = (seconds / 10) % 10;
  SecondOne = seconds % 10;
  ///////

  boolean scrollDigitBool[6] = {SecondOne != lastSecondOne, SecondTen != lastSecondTen, MinuteOne != lastMinuteOne, MinuteTen != lastMinuteTen, HourOne != lastHourOne, HourTen != lastHourTen};
  if (scrollDigitBool[0])
  {
    for (int i = 0; i < 11; i++)
    {
      lastSecondOne++;
      if (scrollDigitBool[1])
      {
        lastSecondTen++;
      }
      if (scrollDigitBool[2])
      {
        lastMinuteOne++;
      }
      if (scrollDigitBool[3])
      {
        lastMinuteTen++;
      }
      if (scrollDigitBool[4])
      {
        lastHourOne++;
      }
      if (scrollDigitBool[5])
      {
        lastHourTen++;
      }
      secondsCombined = (lastSecondTen % 10) | ((lastSecondOne % 10) << 4);
      minutesCombined = (lastMinuteTen % 10) | ((lastMinuteOne % 10) << 4);
      hoursCombined = (lastHourTen % 10) | ((lastHourOne % 10) << 4);
      writeToNixieRAW(hoursCombined, minutesCombined, secondsCombined, divider);
      delay(15);
    }
    if (lastSecondTen == 16)
    {
      lastSecondTen = 0;
      if (lastMinuteTen == 16)
      {
        lastMinuteTen = 0;
        if (twelveHourMode)
        {
          if (lastHourOne == 13)
          {
            lastHourOne = 1;
            lastHourTen = 0;
          }
        }
        else
        {
          if (lastHourOne == 14)
          {
            lastHourOne = 0;
            lastHourTen = 0;
          }
        }
      }
      secondsCombined = (lastSecondTen % 10) | ((lastSecondOne % 10) << 4);
      minutesCombined = (lastMinuteTen % 10) | ((lastMinuteOne % 10) << 4);
      hoursCombined = (lastHourTen % 10) | ((lastHourOne % 10) << 4);
      writeToNixieRAW(hoursCombined, minutesCombined, secondsCombined, divider);
    }
  }

  lastHourTen = (hours / 10) % 10;
  lastHourOne = hours % 10;
  lastMinuteTen = (minutes / 10) % 10;
  lastMinuteOne = minutes % 10;
  lastSecondTen = (seconds / 10) % 10;
  lastSecondOne = seconds % 10;
}

int convertToNixe(int num) //convert 2 digit number to display on nixie tubes
{
  int nixienum;
  if (num == 255) //blank the display
  {
    nixienum = num;
  }
  else
  {
    nixienum = ((num / 10) % 10) | ((num % 10) << 4); //hours (tens digit) or-ed with (ones place shifted 4 left)
  }
  return nixienum;
}
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

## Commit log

2020-04-02 just before removing button, rotary is in it.
2020-04-04 added eagle design files
    [copper_bottom.gbr, copper_top.gbr, drill_1_16.xln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]
2020-04-05 adding pictures, fixing small bugs
    [nixieClock.ino]
